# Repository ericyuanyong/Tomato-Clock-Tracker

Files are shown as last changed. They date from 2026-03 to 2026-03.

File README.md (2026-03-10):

# Tomato Clock Tracker 🍅

## Background

This is a small personal project that records Pomodoro (tomato clock) sessions using a 
[Particle P2](https://store.particle.io/products/p2) device and a 
[Particle Tachyon](https://store.particle.io/products/tachyon) backend.
> *"Knowledge is not free --- you have to pay attention."*

In today's world, it is becoming harder to stay focused. We are
surrounded by smart devices, notifications, and endless streams of
distraction.

At the beginning of **2026**, I decided to take my attention back.\
So I built my own **physical tomato clock**.

The idea is simple:\
when I want to focus, I press a button and commit to **30 minutes of
uninterrupted work**.

------------------------------------------------------------------------

## Features

This project intentionally keeps things simple.\
It has **only two features**:

1.  **Start a 30-minute focus session** by pressing a button.
2.  **Receive a daily email report** showing how many focus sessions
    were completed.

That's it. No apps, no notifications, no distractions.

------------------------------------------------------------------------

## System Architecture

To keep the design simple:

-   **Particle P2** acts as the local controller.
-   **Tachyon** acts as the backend subscriber.

```
    Button press
        ↓
    Particle P2
        ↓
    Particle Cloud (event publish)
        ↓
    Tachyon subscriber
        ↓
    SQLite database
        ↓
    Weekly report script (cron)
        ↓
    Email summary
```

### Components

**Device** - Particle **P2** - Button input - Optional LCD / progress
bar display

**Backend** - Tachyon - Python scripts - SQLite
database - Cron scheduler

------------------------------------------------------------------------

## Reporting

One feature that distinguishes this tomato clock from others is the
**daily email report**.

Every day I receive an email summarizing:

-   total focus sessions
-   total focus time
-   daily breakdown

Example report:

    🍅 Tomato Clock Weekly Report

    Total sessions: 66
    Focus time: 1980 minutes

    Daily breakdown (Mon → Sun):

    Mon | ████                 8
    Tue | ███████              14
    Wed | ███████████          23
    Thu | ███████████████      31
    Fri | ██                   4
    Sat |                      0
    Sun |                      0

> 💡 **Motivation**  
> Checking this report has become a small reward that motivates me to keep improving my focus.

------------------------------------------------------------------------

## Repository Structure

    tomato_clock/
    │
    ├── subscriber.py
    ├── report_and_email.py
    ├── requirements.txt
    ├── tomato.db
    ├── report.log
    └── README.md

------------------------------------------------------------------------

## Requirements

Python 3.10+

Install dependencies:

``` bash
pip install -r requirements.txt
```

Typical dependencies:

    requests
    sseclient-py
    matplotlib

------------------------------------------------------------------------

## Running the Subscriber

The subscriber listens to **Particle Cloud events** and writes them into
the SQLite database.

Run manually:

``` bash
python subscriber.py
```

Recommended: run as a **systemd service**.

------------------------------------------------------------------------

## Scheduling the Report

Use **cron** to send the daily/weekly email report.

Edit crontab:

``` bash
crontab -e
```

Example (Friday 18:00):

``` bash
0 18 * * FRI /home/eric/myvenv/bin/python /home/eric/tomato_clock/report_and_email.py >> /home/eric/tomato_clock/report.log 2>&1
```

------------------------------------------------------------------------

## Limitations

Most of the backend code in this project was developed with the help of
**ChatGPT**.

The most difficult part was configuring **SMTP email sending on the
Tachyon**, especially when working with providers like Outlook or
Gmail.

------------------------------------------------------------------------

## Author

Eric Yuan\
ChatGPT

------------------------------------------------------------------------

## Motivation

This project is not about building a complicated productivity tool.

It is about something much simpler:

> **Take back control of attention.**

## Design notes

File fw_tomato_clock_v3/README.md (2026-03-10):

# airSensor

A Particle project named airSensor

## Welcome to your project!

Every new Particle project is composed of 3 important elements that you'll see have been created in your project directory for airSensor.

#### ```/src``` folder:  
This is the source folder that contains the firmware files for your project. It should *not* be renamed. 
Anything that is in this folder when you compile your project will be sent to our compile service and compiled into a firmware binary for the Particle device that you have targeted.

If your application contains multiple files, they should all be included in the `src` folder. If your firmware depends on Particle libraries, those dependencies are specified in the `project.properties` file referenced below.

#### ```.ino``` file:
This file is the firmware that will run as the primary application on your Particle device. It contains a `setup()` and `loop()` function, and can be written in Wiring or C/C++. For more information about using the Particle firmware API to create firmware for your Particle device, refer to the [Firmware Reference](https://docs.particle.io/reference/firmware/) section of the Particle documentation.

#### ```project.properties``` file:  
This is the file that specifies the name and version number of the libraries that your project depends on. Dependencies are added automatically to your `project.properties` file when you add a library to a project using the `particle library add` command in the CLI or add a library in the Desktop IDE.

## Adding additional files to your project

#### Projects with multiple sources
If you would like add additional files to your application, they should be added to the `/src` folder. All files in the `/src` folder will be sent to the Particle Cloud to produce a compiled binary.

#### Projects with external libraries
If your project includes a library that has not been registered in the Particle libraries system, you should create a new folder named `/lib/<libraryname>/src` under `/<project dir>` and add the `.h`, `.cpp` & `library.properties` files for your library there. Read the [Firmware Libraries guide](https://docs.particle.io/guide/tools-and-features/libraries/) for more details on how to develop libraries. Note that all contents of the `/lib` folder and subfolders will also be sent to the Cloud for compilation.

## Compiling your project

When you're ready to compile your project, make sure you have the correct Particle device target selected and run `particle compile <platform>` in the CLI or click the Compile button in the Desktop IDE. The following files in your project folder will be sent to the compile service:

- Everything in the `/src` folder, including your `.ino` application file
- The `project.properties` file for your project
- Any libraries stored under `lib/<libraryname>/src`

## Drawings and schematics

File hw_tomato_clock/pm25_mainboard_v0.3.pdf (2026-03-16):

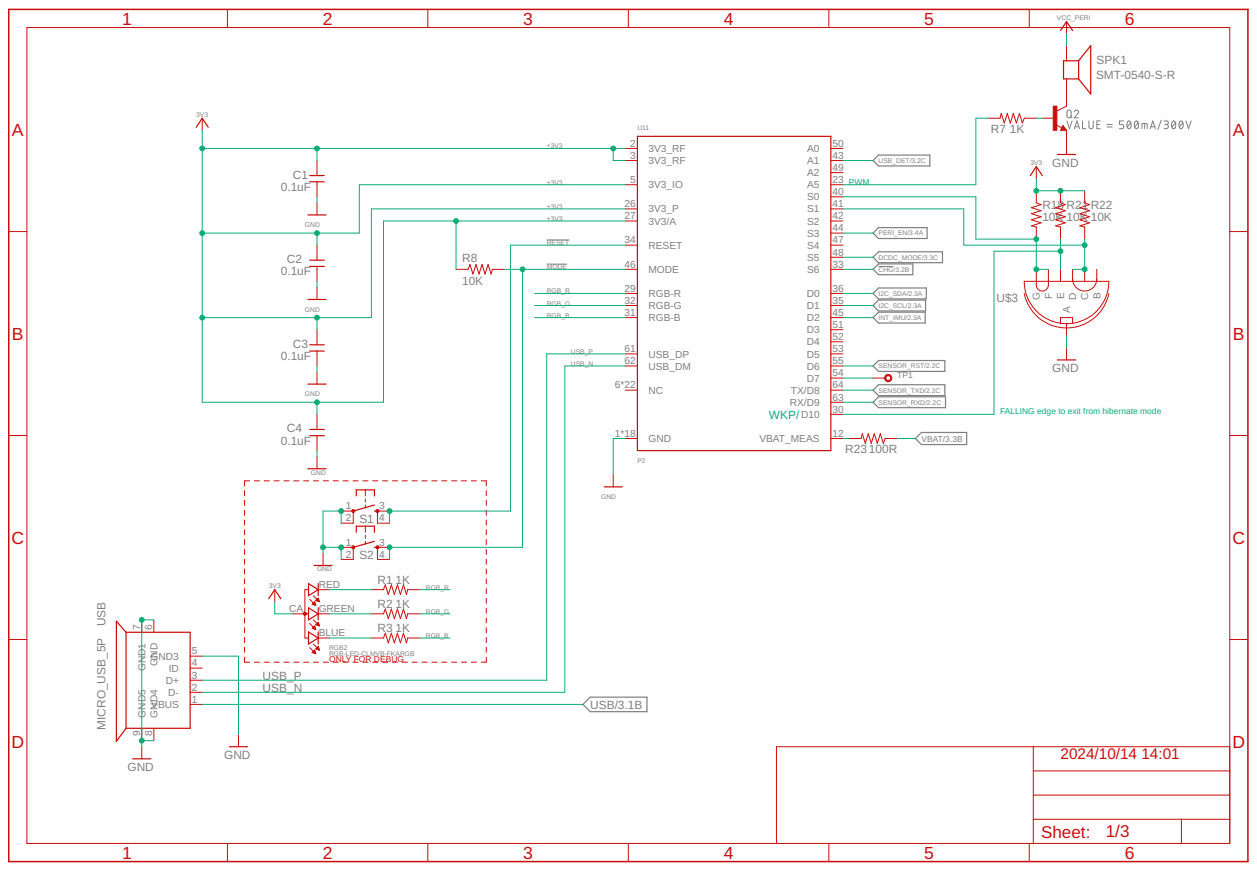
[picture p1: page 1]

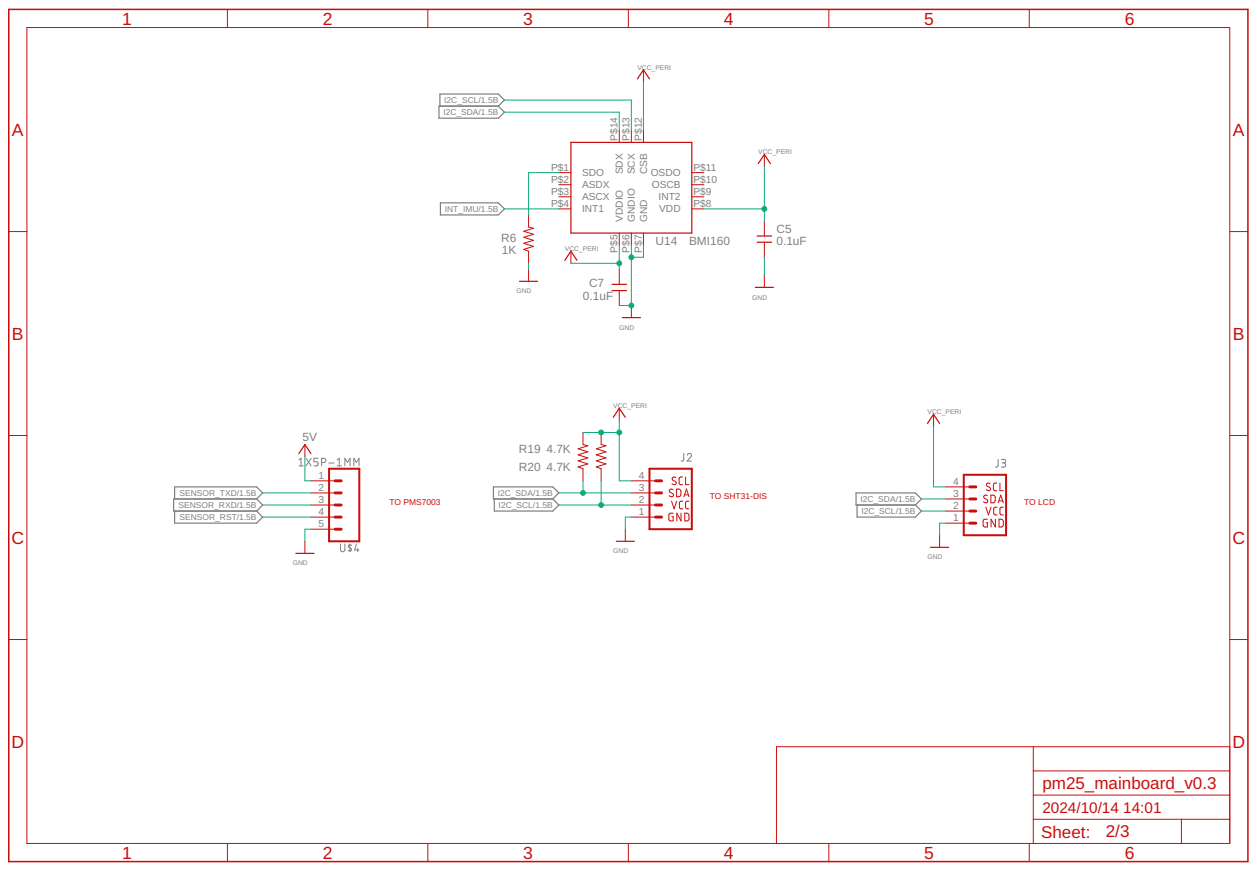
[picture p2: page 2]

VCC_PERI

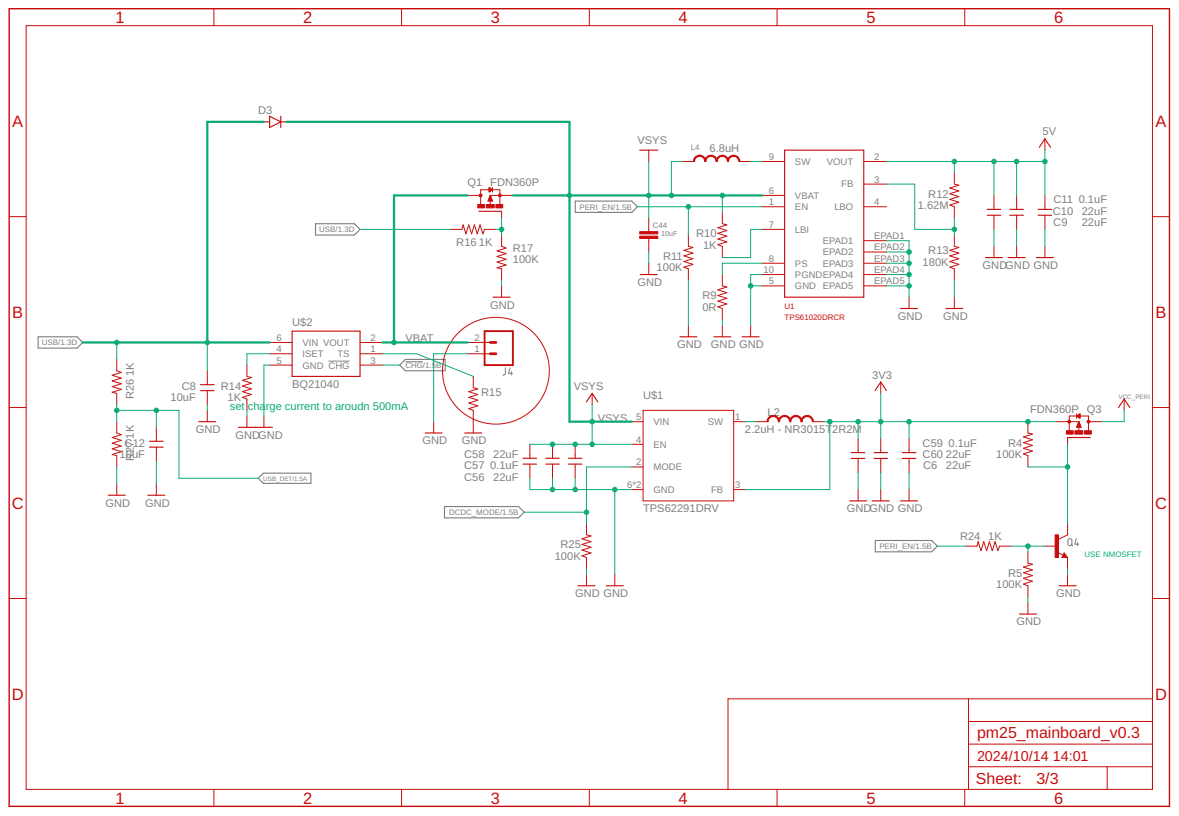
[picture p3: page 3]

set charge current to aroudn 500mA
GND

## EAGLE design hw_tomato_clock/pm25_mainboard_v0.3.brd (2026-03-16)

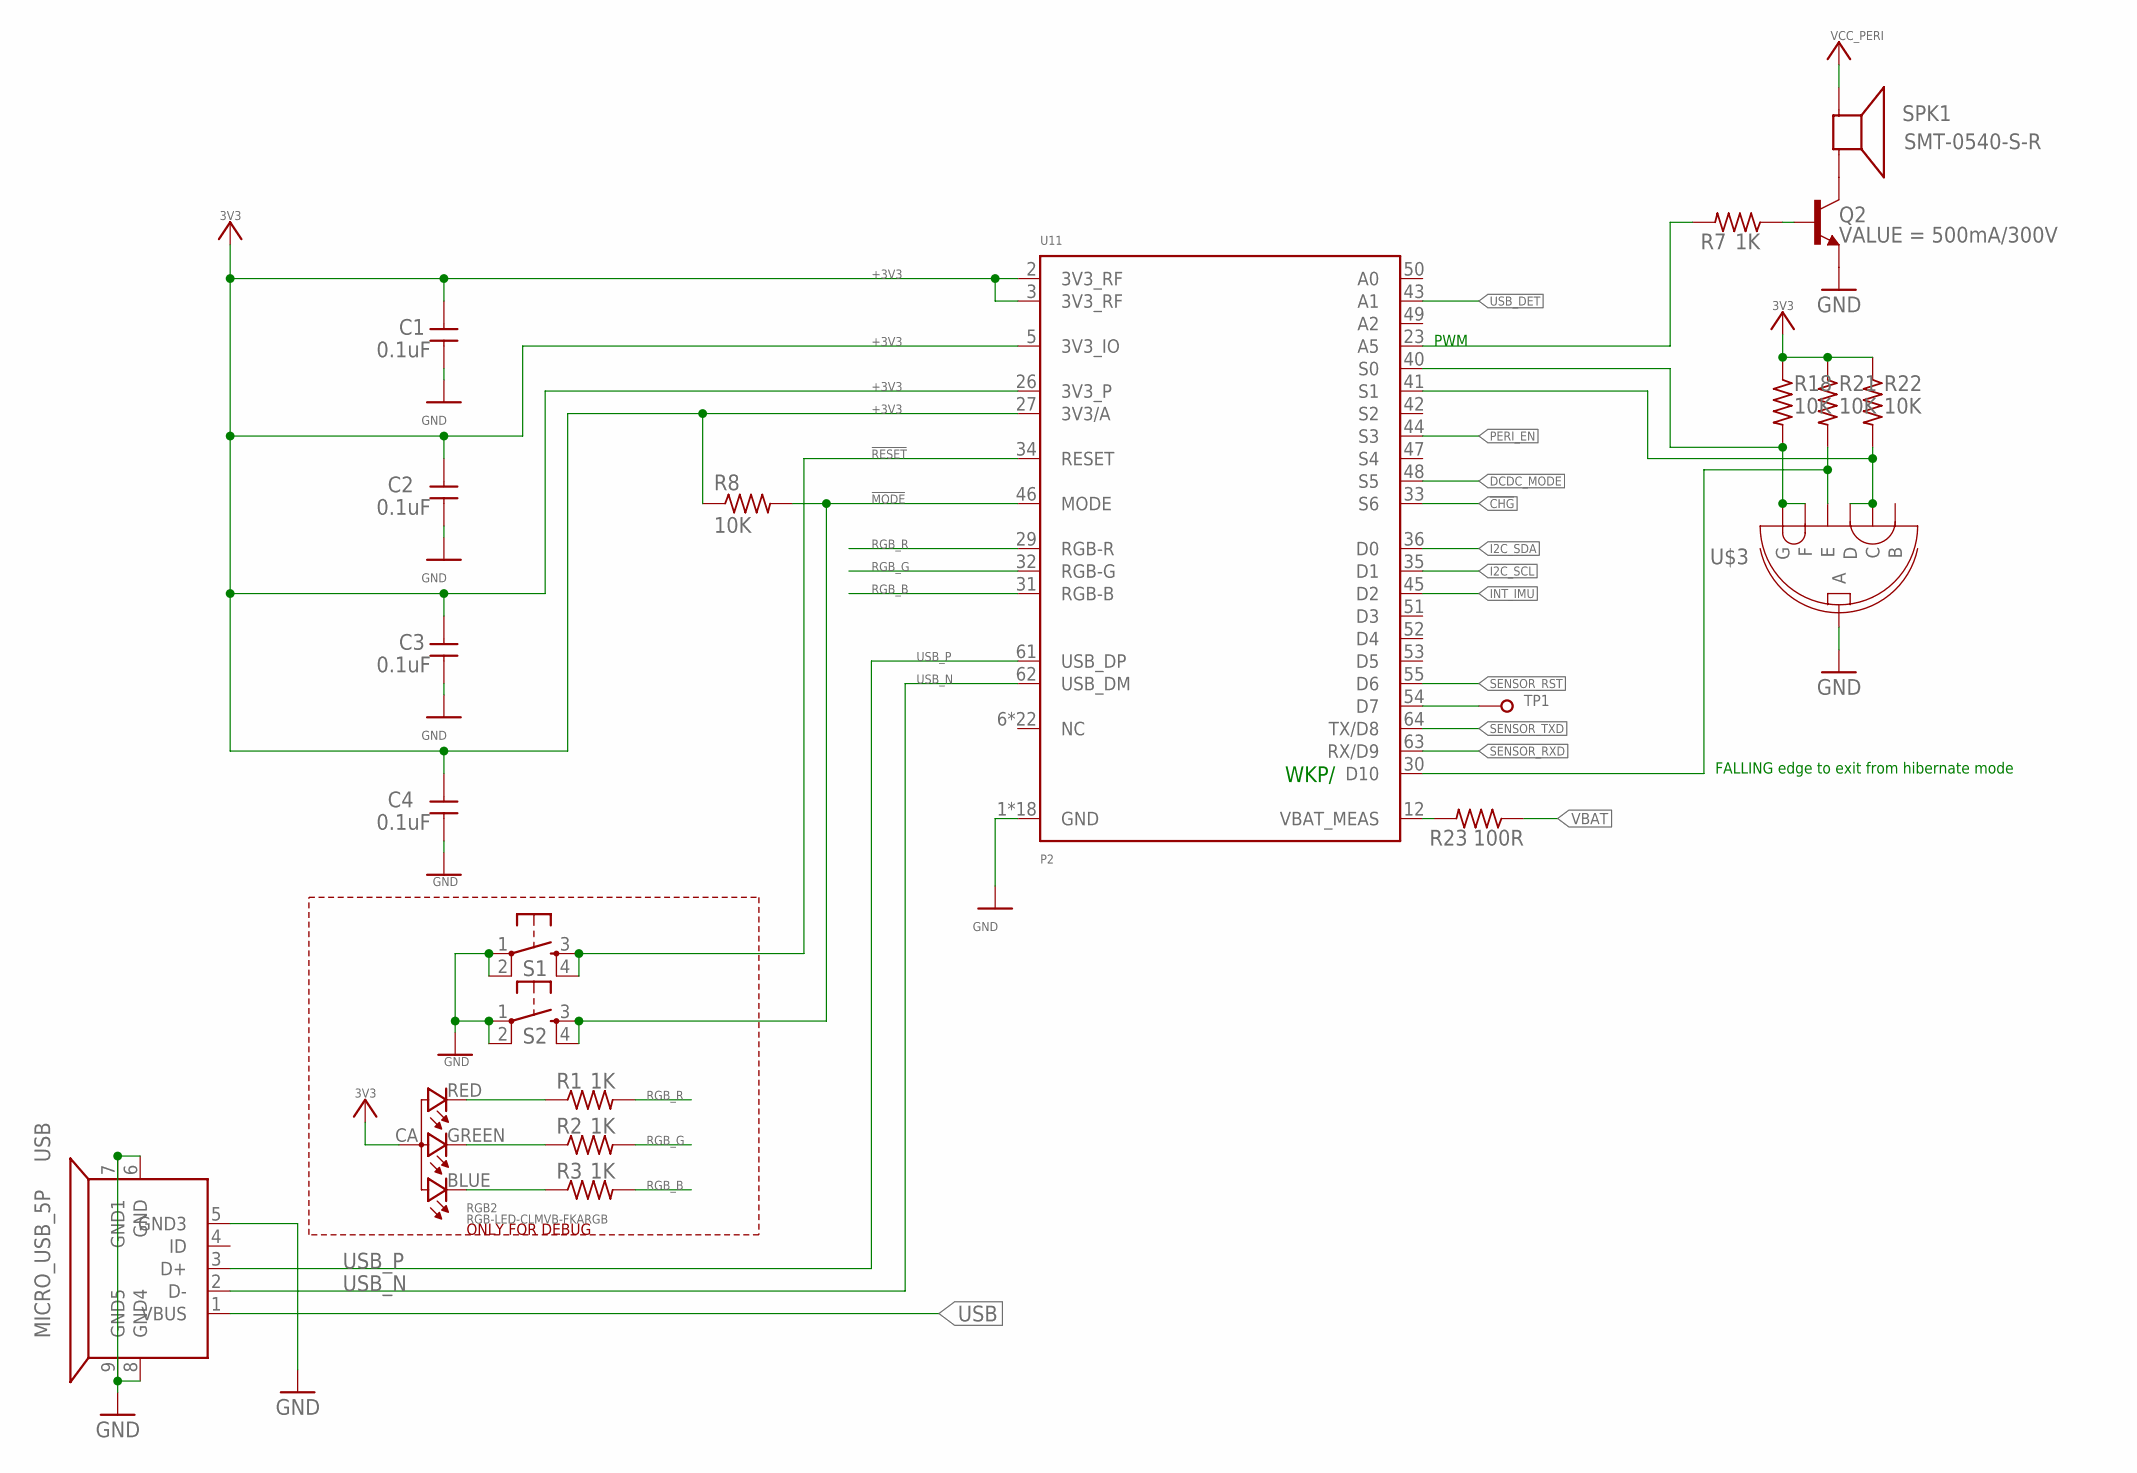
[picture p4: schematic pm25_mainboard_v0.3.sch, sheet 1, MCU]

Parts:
C1, C2, C3, C4: 0.1uF; C0603_P
Q2: 500mA/300V; SOT23-3; MPN MMBTA42-7-F
R1, R2, R3: 1K; R0603_P
R7: 1K; R0603_P; MPN RC-03K102FT
R8, R18, R21, R22: 10K; R0603_P
R23: 100R; R0603_P
RGB2: RGB-LED-CLMVB-FKARGB; PLCC4-2MM-RGB
S1, S2: TAC_SWITCHSMD; TACTILE_SWITCH_SMD
SPK1: SMT-0540-S-R; MPN SMT-0540-S-R
TP1: TP-1.5MM; TP
U11: P2
U$3: MULTI_FUN_SWITCH
USB: MICRO_USB_5P; MICRO_USB

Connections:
!CHG: U11.33 (S6); also elsewhere on the board
!MODE: R8.2, S2.3, S2.4, U11.46 (MODE)
!RESET: S1.3, S1.4, U11.34 (RESET)
+3V3: C1.1, C2.1, C3.1, C4.1, R8.1, R18.1, R21.1, R22.1, RGB2.CA (1), U11.2 (3V3_RF), U11.3 (3V3_RF), U11.5 (3V3_IO), U11.26 (3V3_P), U11.27 (3V3/A); also elsewhere on the board
BUZZER: R7.2, U11.23 (A5)
DCDC_MODE: U11.48 (S5); also elsewhere on the board
GND: C1.2, C2.2, C3.2, C4.2, Q2.2 (E), S1.1, S1.2, S2.1, S2.2, U11.1 (GND), U11.4 (GND), U11.13 (GND), U11.15 (GND), U11.25 (GND), U11.28 (GND), U11.37 (GND), U11.39 (GND), U11.59 (GND), U11.65 (GND), U11.66 (GND), U11.67 (GND), U11.68 (GND), U11.69 (GND), U11.70 (GND), U11.71 (GND), U11.72 (GND), U11.73 (GND), U$3.A, USB.5 (GND3), USB.6 (GND), USB.7 (GND1), USB.8 (GND4), USB.9 (GND5); also elsewhere on the board
I2C_SCL: U11.35 (D1); also elsewhere on the board
I2C_SDA: U11.36 (D0); also elsewhere on the board
INT_IMU: U11.45 (D2); also elsewhere on the board
LEFT: R22.2, U11.41 (S1), U$3.C, U$3.D
MID: R21.2, U11.30 (D10), U$3.E
unnamed: Q2.3 (C), SPK1.- (+)
unnamed: R23.2, U11.12 (VBAT_MEAS)
unnamed: TP1.TP, U11.54 (D7)
unnamed: R1.1, RGB2.RED (4)
unnamed: R2.1, RGB2.GREEN (3)
unnamed: R3.1, RGB2.BLUE (2)
unnamed: Q2.1 (B), R7.1
PERI_EN: U11.44 (S3); also elsewhere on the board
RGB_B: R3.2, U11.31 (RGB-B)
RGB_G: R2.2, U11.32 (RGB-G)
RGB_R: R1.2, U11.29 (RGB-R)
RIGHT: R18.2, U11.40 (S0), U$3.F, U$3.G
SENSOR_RST: U11.55 (D6); also elsewhere on the board
SENSOR_RXD: U11.63 (RX/D9); also elsewhere on the board
SENSOR_TXD: U11.64 (TX/D8); also elsewhere on the board
USB: USB.1 (VBUS); also elsewhere on the board
USB_DET: U11.43 (A1); also elsewhere on the board
USB_N: U11.62 (USB_DM), USB.2 (D-)
USB_P: U11.61 (USB_DP), USB.3 (D+)
VBAT: R23.1; also elsewhere on the board
VCC_PERI: SPK1.+ (-); also elsewhere on the board

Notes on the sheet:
ONLY FOR DEBUG
WKP/
PWM
FALLING edge to exit from hibernate mode

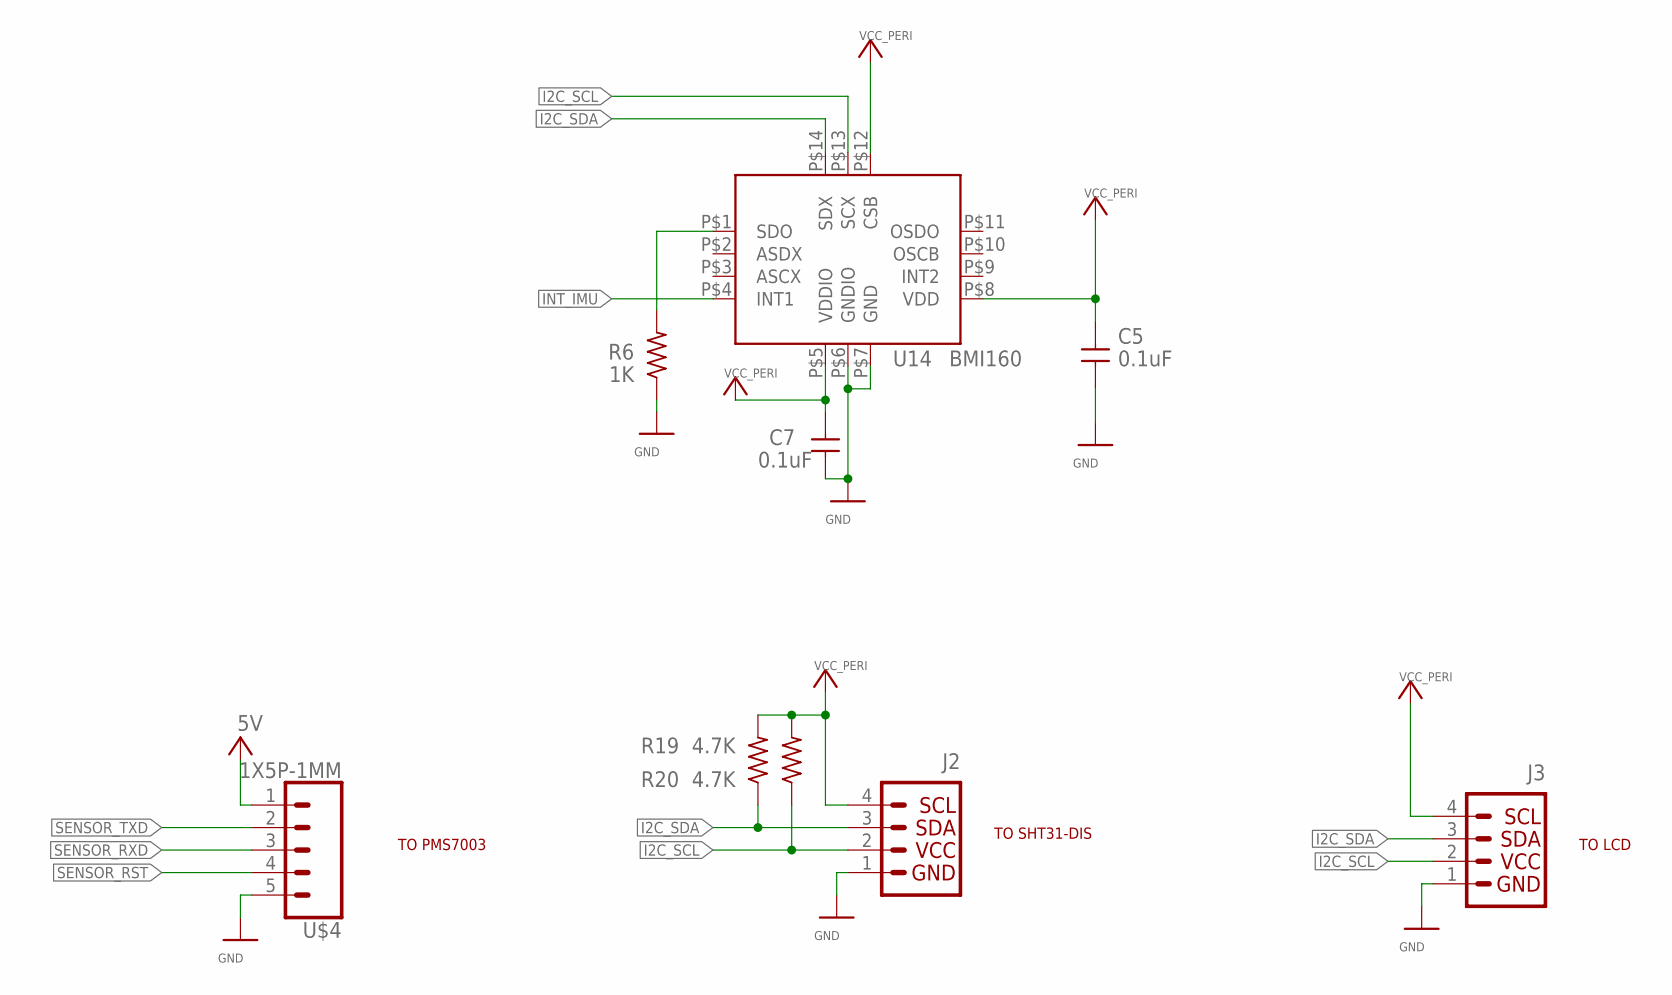
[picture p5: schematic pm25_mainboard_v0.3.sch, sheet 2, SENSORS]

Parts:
C5, C7: 0.1uF; C0603_P
J2, J3: QWIIC_CONNECTORJS-1MM; 1X04_1MM_RA
R6: 1K; R0603_P
R19, R20: 4.7K; R0603_P
U14: BMI160; LGA-14L
U$4: 1X5P-1MM; 1X05-1MM

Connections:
5V: U$4.1; also elsewhere on the board
GND: C5.2, C7.2, J2.1 (GND), J3.1 (GND), R6.1, U14.P$6 (GNDIO), U14.P$7 (GND), U$4.5; also elsewhere on the board
I2C_SCL: J2.2 (VCC), J3.2 (VCC), R20.1, U14.P$13 (SCX); also elsewhere on the board
I2C_SDA: J2.3 (SDA), J3.3 (SDA), R19.1, U14.P$14 (SDX); also elsewhere on the board
INT_IMU: U14.P$4 (INT1); also elsewhere on the board
unnamed: R6.2, U14.P$1 (SDO)
SENSOR_RST: U$4.4; also elsewhere on the board
SENSOR_RXD: U$4.3; also elsewhere on the board
SENSOR_TXD: U$4.2; also elsewhere on the board
VCC_PERI: C5.1, C7.1, J2.4 (SCL), J3.4 (SCL), R19.2, R20.2, U14.P$5 (VDDIO), U14.P$8 (VDD), U14.P$12 (CSB); also elsewhere on the board

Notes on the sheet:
TO PMS7003
TO SHT31-DIS
TO LCD

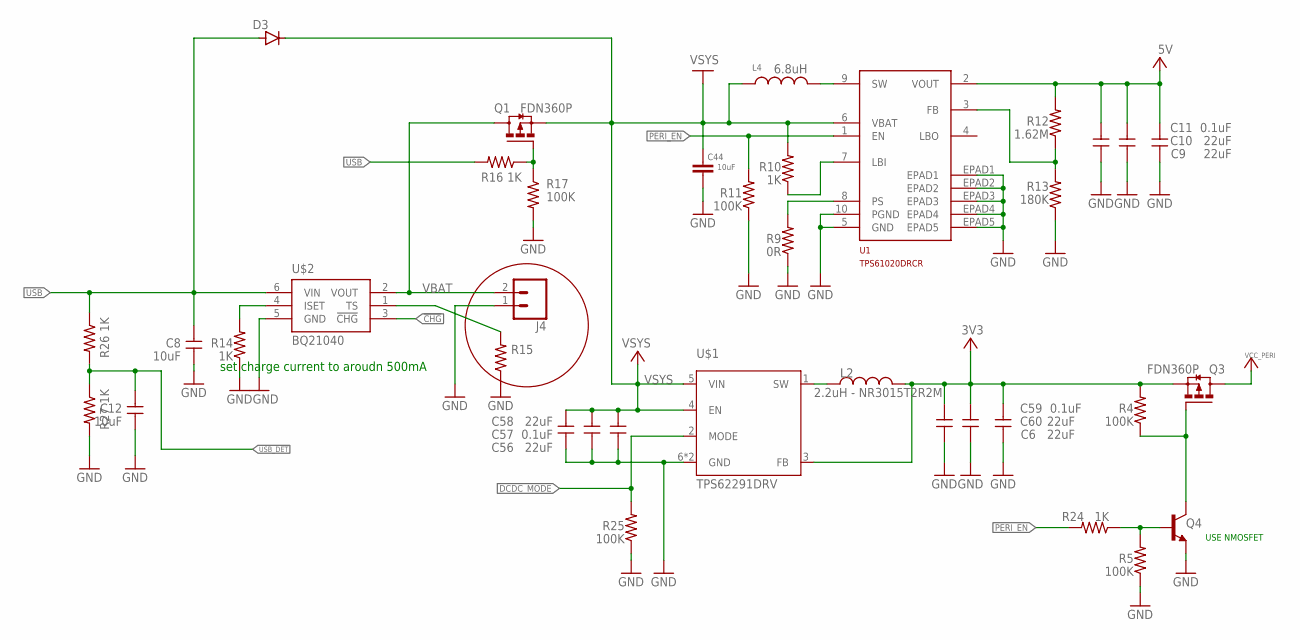
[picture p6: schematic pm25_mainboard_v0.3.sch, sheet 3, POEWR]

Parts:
C6, C10, C11, C56, C58, C60: 22uF; C0603_P
C8, C12: 10uF; C0603_P
C9, C57, C59: 0.1uF; C0603_P
C44: 10uF; C0805_MURATA_GRM21
D3: DIODE-SOD123; SOD123
J4: CONN_02-JST-2MM-SMT; JST-2-SMD
L2: 2.2uH - NR3015T2R2M; INDUCTOR-NR3015; MPN NR3015T2R2M
L4: 6.8uH; CDRH5D28NP-6R2NC
Q1, Q3: FDN360P; SUPER-SOT3
Q4: TRANS_NPN-MMBTA42; SOT23-3; MPN MMBTA42-7-F
R4, R5, R11, R17, R25: 100K; R0603_P
R9: 0R; R0603_P
R10, R14, R16, R24, R26, R27: 1K; R0603_P
R12: 1.62M; R0603_P
R13: 180K; R0603_P
R15: RES_0603; R0603_P
U1: TPS61020DRCR
U$1: TPS62291DRV; S-PWSON-N6
U$2: BQ21040; SOT23-6

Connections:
3V8_SW: L4.P$2 (2), U1.9 (SW)
5V: C9.2, C10.2, C11.2, R12.2, U1.2 (VOUT); also elsewhere on the board
!CHG: U$2.3 (!CHG); also elsewhere on the board
+3V3: C6.2, C59.2, C60.2, L2.2, Q3.2 (S), R4.2, U$1.3 (FB); also elsewhere on the board
DCDC_MODE: R25.2, U$1.2 (MODE); also elsewhere on the board
GND: C6.1, C8.1, C9.1, C10.1, C11.1, C12.1, C44.2, C56.1, C57.1, C58.1, C59.1, C60.1, J4.1 (2), Q4.2 (E), R5.1, R9.1, R11.1, R13.1, R14.1, R15.1, R17.2, R25.1, R27.2, U1.5 (GND), U1.10 (PGND), U1.EPAD1, U1.EPAD2, U1.EPAD3, U1.EPAD4, U1.EPAD5, U$1.6 (GND), U$1.TP (GND), U$2.5 (GND); also elsewhere on the board
unnamed: R9.2, U1.8 (PS)
unnamed: R10.1, U1.7 (LBI)
unnamed: R14.2, U$2.4 (ISET)
unnamed: R12.1, R13.2, U1.3 (FB)
unnamed: Q3.1 (G), Q4.3 (C), R4.1
unnamed: R15.2, U$2.1 (TS)
unnamed: Q1.1 (G), R16.1, R17.1
unnamed: Q4.1 (B), R5.2, R24.1
unnamed: L2.1, U$1.1 (SW)
PERI_EN: R11.2, R24.2, U1.1 (EN); also elsewhere on the board
USB: C8.2, D3.A, R16.2, R26.1, U$2.6 (VIN); also elsewhere on the board
USB_DET: C12.2, R26.2, R27.1; also elsewhere on the board
VBAT: J4.2 (1), Q1.3 (D), U$2.2 (VOUT); also elsewhere on the board
VCC_PERI: Q3.3 (D); also elsewhere on the board
VSYS: C44.1, C56.2, C57.2, C58.2, D3.C, L4.P$1 (1), Q1.2 (S), R10.2, U1.6 (VBAT), U$1.4 (EN), U$1.5 (VIN)

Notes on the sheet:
USE NMOSFET
set charge current to aroudn 500mA

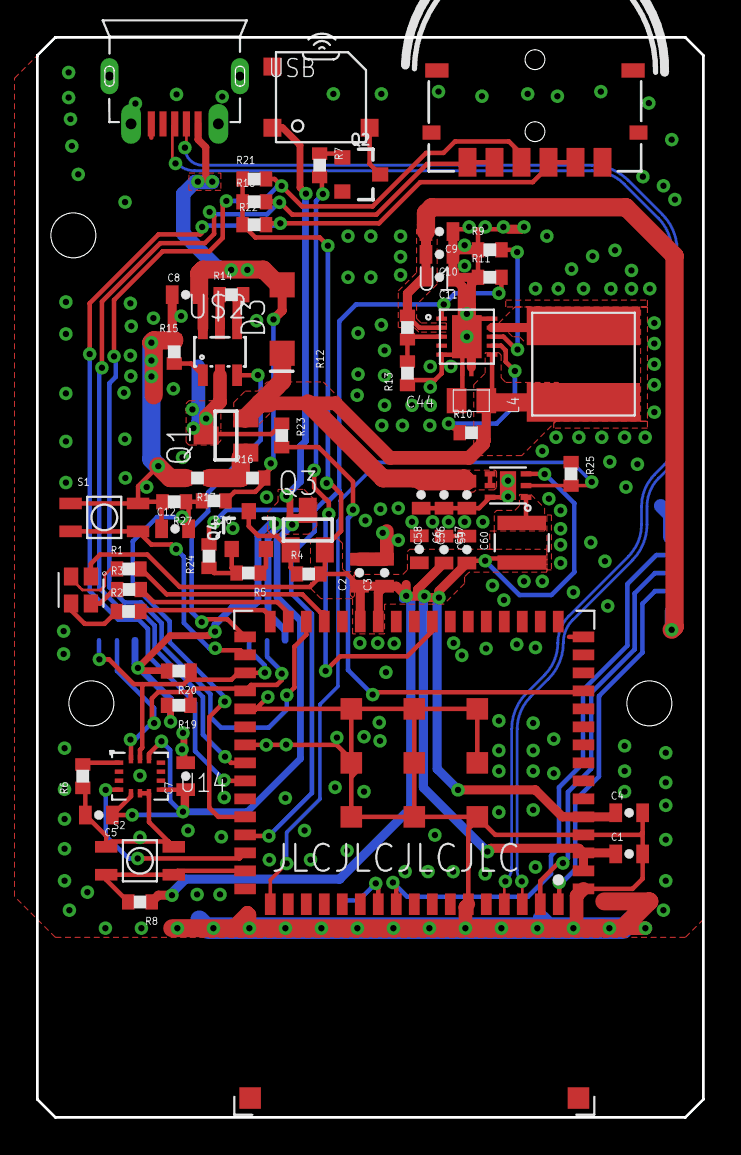
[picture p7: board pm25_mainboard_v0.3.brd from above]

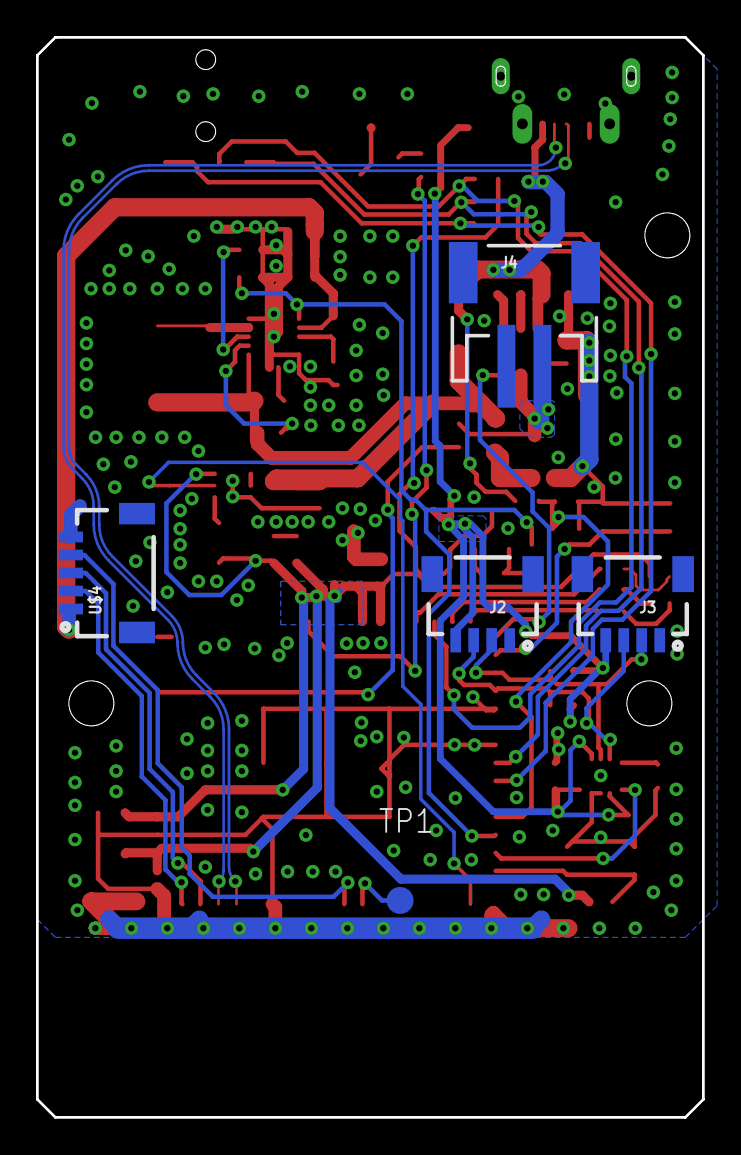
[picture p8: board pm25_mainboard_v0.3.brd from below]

Board: 2 copper layers, 37.0 x 60.0 mm, 68 parts (5 on the bottom side), 46 nets.

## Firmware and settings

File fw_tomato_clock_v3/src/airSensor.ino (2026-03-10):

#include <Wire.h>
#include "./lib/Adafruit_GFX.h"
#include "./lib/Adafruit_SSD1306.h"
#include "./lib/Adafruit_SHT31.h"
#include "./lib/SHT31.h"
#include "./lib/BMI160Gen.h"
#include "./lib/BMI160.h"
#include "./lib/CurieIMU.h"

#include "pinMap.h"
#include "button.h"
#include "oled.h"
#include "pms7003.h"
#include "misc.h"

#define SHT31_ADDRESS   0x44

#define BTN_SCAN_INTERVAL 40

SYSTEM_MODE(AUTOMATIC);
SYSTEM_THREAD(DISABLED); //make sure app wil not start to work until the particle connecetion is done

Adafruit_SHT31 sht31;
//Adafruit_SSD1306 ssd1306 = Adafruit_SSD1306(128,32,&Wire);
BMI160Class bmi160_drv;
Button left_button(BTN_LEFT);
Button right_button(BTN_RIGHT);
Button mid_button(BTN_MID);
PMS7003 pms7003;
MiscClass misc;
OLEDClass oled;




SystemSleepConfiguration config;
const int bmi160_i2c_addr = 0x68;
const int bmi160_interrupt_pin = IMU_INT;   //D2 is the interrupt pin


void setup(){
  delay(1000);
  RGB.control(true);
  if(!Particle.connected()){
    RGB.color(100,0,0);
  }
  else{
    RGB.color(0,0,0);
  }

  Serial.begin(9600);
 // Serial1.begin(9600);
  misc.initiaize();
  misc.dcdc_mode(DCDC_FIX_PWM);
  misc.ext_power_on(true);

  if(!ssd1306.begin(SSD1306_SWITCHCAPVCC, 0x3c)){ 
    Serial.print("Couldn't find ssd1306");
  }
  //seems that dim mode is pretty bright to use.
  ssd1306.dim(true);
  ssd1306.clearDisplay();  
  ssd1306.display(); 

}


/*
only have tomato clock function now
only have three features:
1. press button to enter the tomato clock, it will at first publish a message to particle cloud. It will simply block all the other features as 30 minutes is a dead loop.
2. after clock finished. it will simply turn off the screen. 
3. it will periodically check the battery charge status and if there is a charge action. then the charge led will turns on.
4. it will periodically check if the WiFi connection is stable or not. if not the charge led will turns on.
*/
void loop(){

  static unsigned long button_scan_interval = 0;
  static unsigned long charge_scan_interval = 0;
  static unsigned long network_scan_interval = 0;

  if(millis()-button_scan_interval>=BTN_SCAN_INTERVAL){
    button_scan_interval = millis();
    uint8_t mid_btn = mid_button.pressAction();
    if(mid_btn==1){
      Serial.println("middle button short pressed");
      //around 30 minutes
      misc.ext_power_on(true);
      delay(200);
      if(Particle.connected()){
        RGB.color(0,0,0);
        Particle.publish("tomato/pressed", "start", PRIVATE); 
      }else{
        Particle.connect();
        RGB.color(100,0,0);
      }

      //this need to be initialized everytime when the clock started
      if(!ssd1306.begin(SSD1306_SWITCHCAPVCC, 0x3c)){ 
        Serial.print("Couldn't find ssd1306");
      }
      //seems that dim mode is pretty bright to use.
      ssd1306.dim(true);
      ssd1306.clearDisplay();  
      ssd1306.display(); 

      oled.display_tomato_clock(1);
      tone(BUZZER,400,100);
      ssd1306.clearDisplay();
      ssd1306.display();
      delay(1000);
      misc.ext_power_on(false);
    }
  }
  
  if(millis()-network_scan_interval>= 60000){
    network_scan_interval = millis();
    if(!Particle.connected()){
      RGB.color(100,0,0);
    }else{
      RGB.color(0,0,0);
    }
  }
}

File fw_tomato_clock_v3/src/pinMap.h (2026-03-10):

#ifndef _PINMAP_H_
#define _PINMAP_H_






#define USB_DET     A1     

//buzzer
#define BUZZER      A5     

//swtich
#define BTN_LEFT    S0
#define BTN_RIGHT   S1
#define BTN_MID     D10     //this pin will be used as a wakeup source

//3.3v and 5V peripherial enable
#define PERI_EN     S3

//PSW or fix pwm mode selection for 3.3v dcdc regulator
#define DCDC_MODE   S5

//charger IC
#define CHARGE      S6

//accel IC
#define IMU_INT     D2

//pms7003
#define PMS7003_RST D6     
#define PMS7003_TXD D8
#define PMS7003_RXD D9


#endif

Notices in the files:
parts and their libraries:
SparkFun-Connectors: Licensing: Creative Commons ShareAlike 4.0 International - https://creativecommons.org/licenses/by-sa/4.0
